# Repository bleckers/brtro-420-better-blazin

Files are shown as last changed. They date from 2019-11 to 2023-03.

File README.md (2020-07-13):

# BRTRO-420 Better Blazin' Mod

### IMPORTANT! A user has reported an issue where the firmware can lockup under certain electrical conditions and cause a dangerously high temperature in the oven. A 1.04 release has been issued to include a watchdog and brownout reset to prevent this. Please update to at least the 1.04 release before operating!

Instructions are available in the wiki - https://github.com/bleckers/brtro-420-better-blazin/wiki

Now available on Tindie as a limited run - https://www.tindie.com/products/blecky/brtro-420-better-blazin-mod/



Modify the [BRTRO-420](http://www.charmhigh-tech.com/sale-7840318-hot-2500w-reflow-oven-brt-420-charmhigh-hot-air-infrared-300-300mm-soldering-rework-station.html) reflow oven to have an Arduino based reflow firmware, serial interface, cold junction compensation and zero crossing detection. This mod consists of a board that connects to the existing controller board, which replaces all the control circuitry and microcontroller.

This oven has a few unique features over the popular T-962 oven, which makes it slightly more desirable if you don't mind the higher cost:
 - an internal convection fan built in.
 - a fume exhaust system which you can vent outside.
 - insulation and thermal tape is actually decent, so it doesn't give of nasty smells during operation.
 - overall build quality is much better.
 
However, unlike the [Unified Engineering mods](https://github.com/UnifiedEngineering/T-962-improvements) to the T-692, the BRTRO-420 is slightly more difficult to modify, mostly due to the [unobtainium build chain](https://hackaday.io/project/167324-brtro-420-better-blazin-mod/log/167780-whats-going-to-happen) for its microcontroller along with a few other design issues such as a poor and noisy thermocouple interface. So the decision was made to spin up a mod board that can be soldered to the bottom of the existing board. This mod board is based on the ATSAMC21 which is a native 5V ARM processor, so it works well with the existing interfaces, without requiring level conversion.

The new firmware keeps the same profile nomenclature as the original oven, so there isn't too much adjustment to the new firmware. However, it is completely written from scratch, so the profile modification workflow is a bit easier now. Note, to change the temperature in the profile edit menu, you hold the OK button on the value you want to edit and then you press the UP/DOWN arrows to adjust the value. Settings are stored automatically once exiting the profile editing screen (you will get a notification on the screen about settings being stored). 

Mod Image

Blog entries about the project are here - https://hackaday.io/project/167324-brtro-420-better-blazin-mod

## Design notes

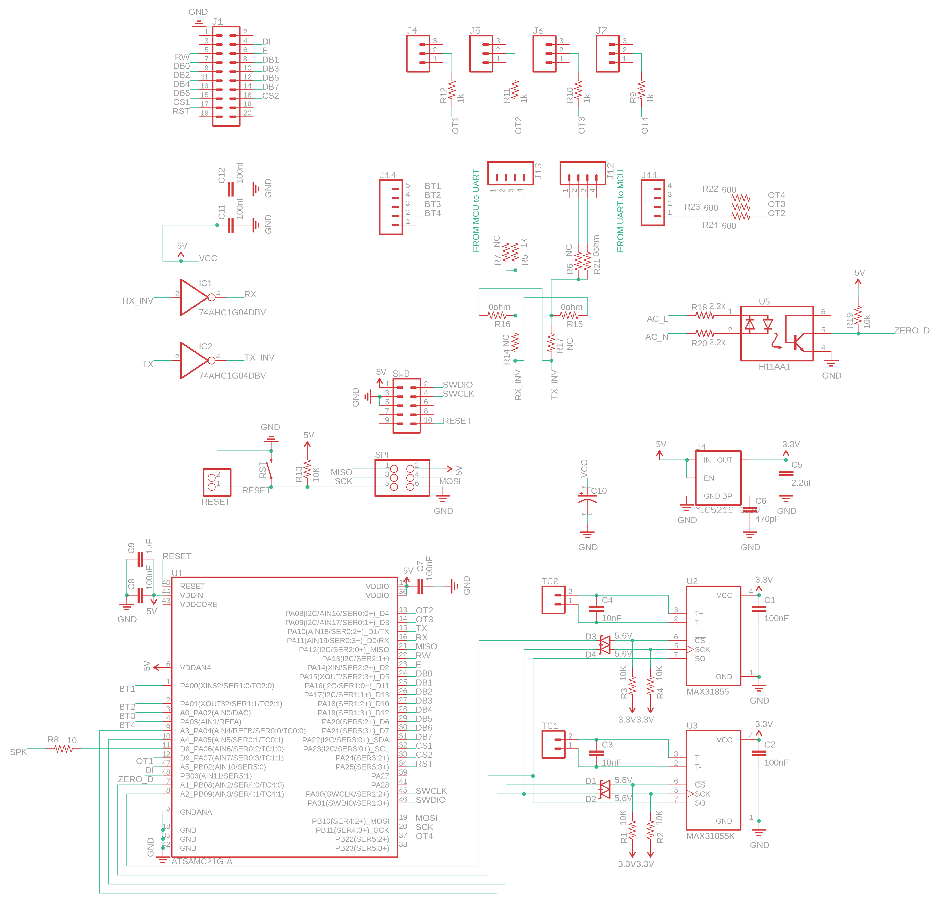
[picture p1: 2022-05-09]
schematic.png

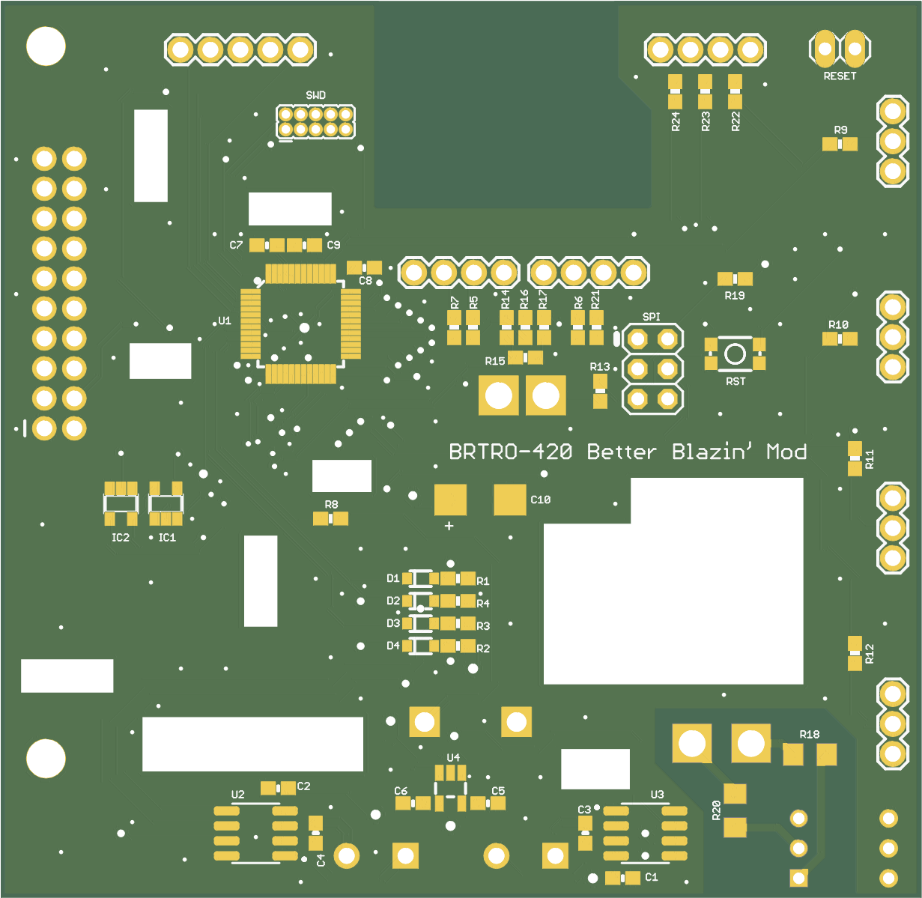
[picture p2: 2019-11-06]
board-gerbers_Combined_Top.png

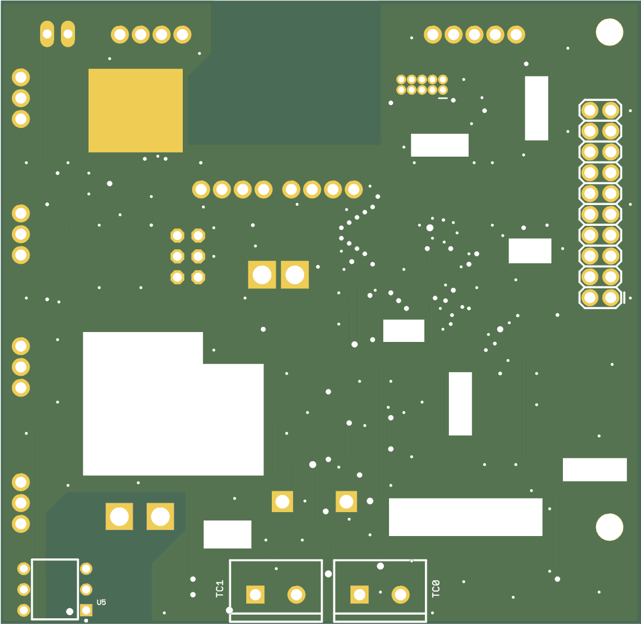
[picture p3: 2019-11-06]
board-gerbers_Combined_Bottom.png

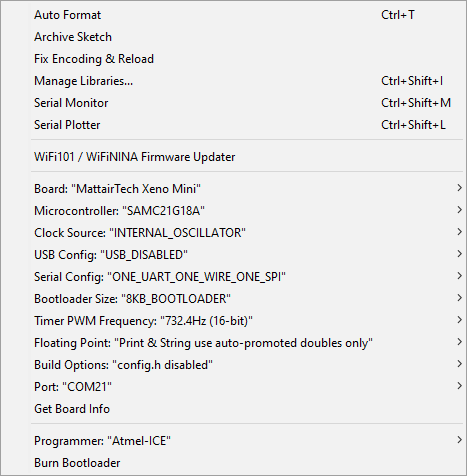
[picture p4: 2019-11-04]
settings.png

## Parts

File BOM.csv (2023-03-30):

Qty | Value | Device | Package | Parts | Description
2 |  | CONN_025MM | SCREWTERMINAL-5MM-2 | TC0, TC1 | Multi connection point. Often used as Generic Header-pin footprint for 0.1 inch spaced/style header connections
1 | 47uF | CPOL-USC/6032-28R | C/6032-28R | C10 | POLARIZED CAPACITOR, American symbol
3 | 0ohm | RESISTOR0603-RES | 0603-RES | R15, R16, R21 | Resistor
1 | 10ohm | RESISTOR0603-RES | 0603-RES | R8 | Resistor
4 | 100nF | CAP0603-CAP | 0603-CAP | C1, C2, C7, C8 | Capacitor
5 | 10K | RESISTOR0603-RES | 0603-RES | R1, R2, R3, R4, R13, R19 | Resistor
2 | 10nF | CAP0603-CAP | 0603-CAP | C3, C4 | Capacitor
4 | 1k | RESISTOR0603-RES | 0603-RES | R5, R9, R10, R11, R12 | Resistor
1 | 1uF | CAP0603-CAP | 0603-CAP | C9 | Capacitor
2 | 2.2k | R-US_R1206 | R1206 | R18, R20 | RESISTOR, American symbol
1 | 2.2uF | CAP0603-CAP | 0603-CAP | C5 | Capacitor
1 | 470pF | CAP0603-CAP | 0603-CAP | C6 | Capacitor
4 | MMSZ5232BS-7-F | 5.6V Zener DIODE | SOD-323 | D1, D2, D3, D4 | Zener Diode
4 | 600 | RESISTOR0603-RES | 0603-RES | R22, R23, R24 | Resistor
2 | 74AHC1G04DBV Or Equivalent | 74AHC1G04DBV | SOT23-5 | IC1, IC2 | INVERTER Gate
1 | ATSAMC21G18A | ATSAMC21G-A | TQFP-48 | U1 | Atmel SAMD21G SMART ARM-Based Microcontroller
1 | H11AA1 | H11AA1 | DIP762W50P254L730H410Q6 | U5 | Optocoupler
2 | MAX31855K | MAX31855K | SOIC127P600X175-8N | U2,U3 | Cold-Junction Compensated Thermocouple-to-Digital Converter
1 | MIC5219 3.3V | V_REG_MIC52193.3V | SOT23-5 | U4 | V_REG MIC5219
1 | MOMENTARY-SWITCH-SPST-SMD-4.6X2.8MM | MOMENTARY-SWITCH-SPST-SMD-4.6X2.8MM | TACTILE_SWITCH_SMD_4.6X2.8MM | S1 | Momentary Switch (Pushbutton) - SPST
3 | NC | RESISTOR0603-RES | 0603-RES | R7, R14, R17,R6 | Resistor

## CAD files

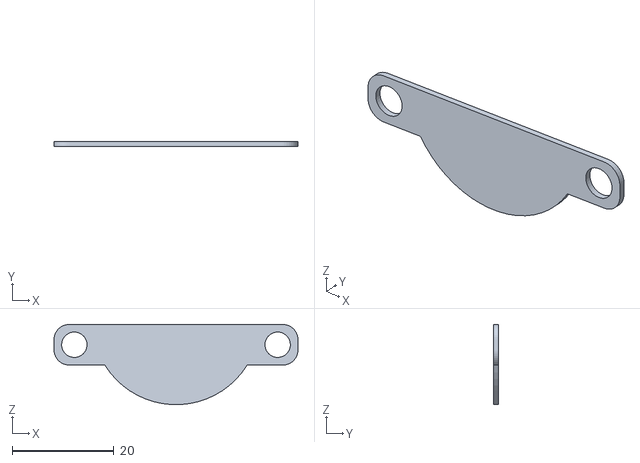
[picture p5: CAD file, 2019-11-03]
fanshim.STL
48.0 x 1.00 x 15.8

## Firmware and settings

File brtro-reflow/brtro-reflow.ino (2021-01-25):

#include "MAX31855soft.h" //https://github.com/enjoyneering/MAX31855
#include <U8g2lib.h> //https://github.com/olikraus/u8g2
//#include "splash-brt.h"
#include "splash-chm.h"
#include "helper.h"
#include "FlashStorage.h"
#include "PID_v1.h"
#include "pidautotuner.h"
#include "variables.h"
#include "menu.h"
#include "serial.h"
#include "watchdog.h"

#define VERSION "V1.04"

bool watchdogReset = false;

double shouldBeTemp;
uint8_t thermocoupleFailCount = 0;

uint8_t fanValue;
uint8_t heaterValueChan0;

double SetpointChan0;
double InputChan0;
double OutputChan0;

uint8_t heaterValueChan1;

double SetpointChan1;
double InputChan1;
double OutputChan1;

PID3_t heaterPIDChan0 = { PID_KP_PREHEAT_C0, PID_KI_PREHEAT_C0, PID_KD_PREHEAT_C0, PID_KP_SOAK_C0, PID_KI_SOAK_C0, PID_KD_SOAK_C0, PID_KP_REFLOW_C0, PID_KI_REFLOW_C0, PID_KD_REFLOW_C0 };
PID3_t heaterPIDChan1 = { PID_KP_PREHEAT_C1, PID_KI_PREHEAT_C1, PID_KD_PREHEAT_C1, PID_KP_SOAK_C1, PID_KI_SOAK_C1, PID_KD_SOAK_C1, PID_KP_REFLOW_C1, PID_KI_REFLOW_C1, PID_KD_REFLOW_C1 };
PID_t fanPID    = { 10.00, 0.03, 10.00 }; //{ 1.00, 0.03, 10.00 };

PID PIDChan0(&InputChan0, &OutputChan0, &SetpointChan0, heaterPIDChan0.Kp_PREHEAT, heaterPIDChan0.Ki_PREHEAT, heaterPIDChan0.Kd_PREHEAT, DIRECT);

PIDAutotuner tunerChan0 = PIDAutotuner();

PID PIDChan1(&InputChan1, &OutputChan1, &SetpointChan1, heaterPIDChan1.Kp_PREHEAT, heaterPIDChan1.Ki_PREHEAT, heaterPIDChan1.Kd_PREHEAT, DIRECT);

PIDAutotuner tunerChan1 = PIDAutotuner();

StoredVar storedVar;

int currentState = IDLEM;

double rampRateChan0 = 0;
double rampRateChan1 = 0;

volatile int frontState = 0;
volatile int backState = 0;
volatile int convectionState = 0;
volatile int exhaustState = 0;

extern U8G2_KS0108_128X64_F u8g2;
extern U8G2LOG u8g2log;
extern uint8_t u8log_buffer[];
extern int errorTimeout;

bool beepState = true;

bool saved = true;
int writeTimeout = -1;
FlashStorage(storedVarFlash, StoredVar);

MAX31855soft MAX31855_0(CSU2, SO, SCK);
MAX31855soft MAX31855_1(CSU3, SO, SCK);

double tc0History[NUMBER_OF_TEMP_AVERAGES] = {0};
double tc1History[NUMBER_OF_TEMP_AVERAGES] = {0};

int averagesCount = 0;

int tempHistoryHead = 0;

double tc0Temp; //Back by default
double tc1Temp; //Front by default
double backTemp;
double frontTemp;
int tcState = 0; //0 normal (Back == TC0, Front == TC1), 1 swapped (Back == TC1, Front == TC0), 2 averaging (Back=Front=(TC0+TC1)/2)

double tc0PrevTemp;
double tc1PrevTemp;

int tc0Detect = MAX31855_THERMOCOUPLE_OK;
int tc1Detect = MAX31855_THERMOCOUPLE_OK;

int currentProfile = 1;
ReflowProfile profiles[MAX_PROFILES + 1]; //Don't use 0 profile

double boardTemp;

int currentMenuID = 0;

unsigned long reflowStartTime = 0;

#define buttonStateTimeout 5

volatile int buttonStatePLUS = 0;
volatile int buttonStateMINUS = 0;
volatile int buttonStateBACK = 0;
volatile int buttonStateOK = 0;

int menuState = 0;
int prevMenuState = 0;
int buttonBACK = 1;
int prevButtonBACK = 1;
unsigned long previousTimeUpdateTemp = 0;
unsigned long previousTimeReadTemp = 0;

int enableMenu = 1;

bool celsiusMode = true; //true is celcius, false is farenheit

int reflow = 0;
unsigned long previousTimeReflowDisplayUpdate = 0;
unsigned long currentReflowSeconds = 0;
unsigned long previousTempDisplayUpdate = 0;

unsigned long prevTempLoopMillis;
unsigned long currentTempLoopMillis;

unsigned long secondsMillisStartChan0;
unsigned long secondsMillisStartChan1;

unsigned long startStateMillis;

int previousState = IDLEM;

uint32_t lastRampTicks;

double startTemp = 0;

bool valueChanged = false;
int profileValueBeingEdited = 0;

int previousSavedProfile;

int currentPIDEditSelection = 0;

unsigned long pollRate = 1000;

double previousRateDisplayTemp0 = 0;

double previousRateDisplayTemp1 = 0;

boolean tuning = false;

boolean currentStateAutotuned = false;

boolean debug = false;

void plusPress()
{
  if (buttonStatePLUS == 0)
    buttonStatePLUS = buttonStateTimeout;
}

void minusPress()
{
  if (buttonStateMINUS == 0)
    buttonStateMINUS = buttonStateTimeout;
}

void okPress()
{
  if (buttonStateOK == 0)
    buttonStateOK = buttonStateTimeout;
}

void zeroCrossing()
{
  int state = digitalRead(ZER_D);

  if (state == 0) //We're in falling
  {
    if (frontState == 1) //Turn on
    {
      digitalWrite(FRONT_HEATER, 0);
    }
    if (backState == 1) //Turn on
    {
      digitalWrite(BACK_HEATER, 0);
    }
    if (convectionState == 1) //Turn on
    {
      digitalWrite(CONVECTION, 0);
    }
    if (exhaustState == 1) //Turn on
    {
      digitalWrite(EXHAUST, 0);
    }
  } else { //We're in rising
    if (frontState == 0)
    { //Turn off
      digitalWrite(FRONT_HEATER, 1);
    }
    if (backState == 0)
    { //Turn off
      digitalWrite(BACK_HEATER, 1);
    }
    if (convectionState == 0)
    { //Turn off
      digitalWrite(CONVECTION, 1);
    }
    if (exhaustState == 0)
    { //Turn off
      digitalWrite(EXHAUST, 1);
    }
  }
}

void loadSettings()
{
  for (int i = 0; i < MAX_PROFILES; i++)
  {
    profiles[i + 1].PreHtTemp = storedVar.profiles[i].PreHtTemp;
    profiles[i + 1].HeatTemp = storedVar.profiles[i].HeatTemp;
    profiles[i + 1].RefTemp = storedVar.profiles[i].RefTemp;
    profiles[i + 1].RefKpTemp = storedVar.profiles[i].RefKpTemp;
    profiles[i + 1].CoolTemp = storedVar.profiles[i].CoolTemp;

    profiles[i + 1].PreHtTime = storedVar.profiles[i].PreHtTime;
    profiles[i + 1].HeatTime = storedVar.profiles[i].HeatTime;
    profiles[i + 1].RefTime = storedVar.profiles[i].RefTime;
    profiles[i + 1].RefKpTime = storedVar.profiles[i].RefKpTime;
    profiles[i + 1].CoolTime = storedVar.profiles[i].CoolTime;
  }

  heaterPIDChan0.Kp_PREHEAT = storedVar.KpChan0_PREHEAT;
  heaterPIDChan0.Ki_PREHEAT = storedVar.KiChan0_PREHEAT;
  heaterPIDChan0.Kd_PREHEAT = storedVar.KdChan0_PREHEAT;
  heaterPIDChan1.Kp_PREHEAT = storedVar.KpChan1_PREHEAT;
  heaterPIDChan1.Ki_PREHEAT = storedVar.KiChan1_PREHEAT;
  heaterPIDChan1.Kd_PREHEAT = storedVar.KdChan1_PREHEAT;

  heaterPIDChan0.Kp_SOAK = storedVar.KpChan0_SOAK;
  heaterPIDChan0.Ki_SOAK = storedVar.KiChan0_SOAK;
  heaterPIDChan0.Kd_SOAK = storedVar.KdChan0_SOAK;
  heaterPIDChan1.Kp_SOAK = storedVar.KpChan1_SOAK;
  heaterPIDChan1.Ki_SOAK = storedVar.KiChan1_SOAK;
  heaterPIDChan1.Kd_SOAK = storedVar.KdChan1_SOAK;

  heaterPIDChan0.Kp_REFLOW = storedVar.KpChan0_REFLOW;
  heaterPIDChan0.Ki_REFLOW = storedVar.KiChan0_REFLOW;
  heaterPIDChan0.Kd_REFLOW = storedVar.KdChan0_REFLOW;
  heaterPIDChan1.Kp_REFLOW = storedVar.KpChan1_REFLOW;
  heaterPIDChan1.Ki_REFLOW = storedVar.KiChan1_REFLOW;
  heaterPIDChan1.Kd_REFLOW = storedVar.KdChan1_REFLOW;

  tcState = storedVar.tcState;

  celsiusMode = storedVar.celsiusMode;

  beepState = storedVar.beepState;

  PIDChan0.SetTunings(heaterPIDChan0.Kp_PREHEAT, heaterPIDChan0.Ki_PREHEAT, heaterPIDChan0.Kd_PREHEAT);
  PIDChan1.SetTunings(heaterPIDChan1.Kp_PREHEAT, heaterPIDChan1.Ki_PREHEAT, heaterPIDChan1.Kd_PREHEAT);

  currentProfile = storedVar.profile;
}

void checkSerial()
{
  while (Serial.available())
  {
    char c = Serial.read();
    if (c == '#')
    {
      /* Set bootloader check value and reboot */
      BOOT_MAGIC_VALUE = BOOT_MAGIC_BOOTLOADER_ENABLE;
      NVIC_SystemReset();//software reset
    }
    else if (c == 'R') //Command to reset for debug purposes
    {
      BOOT_MAGIC_VALUE = 0;
      NVIC_SystemReset();//software reset
    }
    else if (c == 'T') //Print Temps
    {
      if (celsiusMode) Serial.print(backTemp);
      else Serial.print(cToF(backTemp));
      Serial.print(",");
      if (celsiusMode) Serial.println(frontTemp);
      else Serial.println(cToF(frontTemp));
    }
    else if (c == ' ' || c == 'c' || c == 'C') //OK: Spacebar Pressed (or c)
    {
      buttonStateOK = 1; //Will trigger next loop
    }
    else if (c == 'b' || c == 'B' || c == 'v' || c == 'V') //Back: b pressed (or v)
    {
      buttonStateBACK = buttonStateTimeout; //Will trigger next loop (note this is handled differently to other buttons
    }
    else if (c == 'p' || c == 'P' || c == 'z' || c == 'Z') //Plus: p pressed (or z)
    {
      buttonStatePLUS = 1; //Will trigger next loop
    }
    else if (c == 'm' || c == 'M' || c == 'x' || c == 'X') //Minus: m pressed (or x)
    {
      buttonStateMINUS = 1; //Will trigger next loop
    }
    else if (c == '*')
    {
      debug = true;
    }
    else if (c == '8')
    {
      debug = false;
    }
    else if (c == 'A' && debug) //All outputs on for testing (will auto turn off in rest of code)
    {
      frontState = 1;
      digitalWrite(FRONT_HEATER, 0);
      backState = 1;
      digitalWrite(BACK_HEATER, 0);
      convectionState = 1;
      digitalWrite(CONVECTION, 0);
      exhaustState = 1;
      digitalWrite(EXHAUST, 0);
      digitalWrite(SPK, 1);
    }
    else if (c == '~') //Print screen to XBM
    {
      Serial.println("");
      Serial.println("");
      u8g2.writeBufferXBM(Serial); //Requires u8g2 v2.27 (latest from https://github.com/olikraus/U8g2_Arduino)
      Serial.println("");
      Serial.println("");
    }
  }
}

void setup()
{
  //Set the outputs first to prevent powering on elements
  setOutputs();

  /* \/ \/ \/ Keep below here \/ \/ \/ */
  /* Protect against bad code requiring ICSP flashing, do not remove */
  /* This allows us to hold # on startup if we had a bad flash */
  Serial.begin(115200);
  int countdown = 1000;
  while (countdown > 0)
  {
    checkSerial();
    countdown--;
    delay(1);
  }
  /* /\ /\ /\ Keep above here /\ /\ /\ */

  if (RSTC->RCAUSE.reg == RSTC_RCAUSE_WDT) {
    Serial.println("Reset requested by Watchdog");
    watchdogReset = true;
  }
  if (RSTC->RCAUSE.reg == RSTC_RCAUSE_BODVDD) {
    Serial.println("Reset requested by BOD");
    watchdogReset = true;
  }

  bod_setup();
  watchdog_setup();

  u8g2.begin();
  //u8g2.clearBuffer();

  u8g2.drawXBM(0, 0, splash_width, splash_height, splash_bits);

  u8g2.setFont(u8g2_font_profont11_mr); // set the font for the terminal window
  u8g2.drawStr(98, 59, VERSION);

  u8g2.sendBuffer();

  u8g2.setFont(u8g2_font_tom_thumb_4x6_mf); // set the font for the terminal window

  u8g2log.begin(U8LOG_WIDTH, U8LOG_HEIGHT, u8log_buffer); // connect to u8g2, assign buffer
  u8g2log.setLineHeightOffset(0);                         // set extra space between lines in pixel, this can be negative
  //u8g2log.setRedrawMode(0);   // 0: Update screen with newline, 1: Update screen for every char

  attachInterrupt(digitalPinToInterrupt(PLUS), plusPress, FALLING);
  attachInterrupt(digitalPinToInterrupt(MINUS), minusPress, FALLING);
  attachInterrupt(digitalPinToInterrupt(OK), okPress, FALLING);

  //BACK button is not on interrupt

  attachInterrupt(digitalPinToInterrupt(ZER_D), zeroCrossing, CHANGE);

  /* start MAX31855 */
  MAX31855_0.begin();
  MAX31855_1.begin();

  /* Get EEPROM Settings */
  storedVar = storedVarFlash.read();
  if (storedVar.valid == false) //Should be false after new code write
  {
    restoreDefaults(&storedVar);
  }

  loadSettings();

  previousSavedProfile = currentProfile; //Used to reduce writes to flash on a common menu function

  PIDChan0.SetOutputLimits(0, 100); // max output 100%
  PIDChan0.SetMode(AUTOMATIC);

  PIDChan1.SetOutputLimits(0, 100); // max output 100%
  PIDChan1.SetMode(AUTOMATIC);

  delay(2000);

  u8g2.clearBuffer();

  drawScreen();
  drawMenu(0); //Draw main menu
  drawMenuBox(0);
  drawProfile(profiles, tc1Temp, currentProfile);

  u8g2.sendBuffer();
}
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
void loop()
{
  /* Back button not on interrupt */
  buttonBACK = digitalRead(BACK);
  if (buttonBACK == 0 && prevButtonBACK == 1 && buttonStateBACK == 0)
  {
    buttonStateBACK = buttonStateTimeout;
  }

  prevButtonBACK = buttonBACK;

  if (buttonStateMINUS == 1 && buttonStatePLUS == 1)
  {
    //Ignore
  }
  else if (buttonStateMINUS == 1)
  {
    if (debug) Serial.println("Minus Pressed");
    if (enableMenu == 1)
    {
      prevMenuState = menuState;

      if (currentMenuID == 5)
      {
        if (menuState == 2 && digitalRead(OK) == 0)
        {
          delay(1); //noise reduction delay
          if (digitalRead(OK) == 0)
          {
            editProfileTemp(profileValueBeingEdited, profiles, currentProfile, false);
            profileEdited();
          }
        }
        else if (menuState == 4 && digitalRead(OK) == 0)
        {
          delay(1); //noise reduction delay
          if (digitalRead(OK) == 0)
          {
            editProfileTime(profileValueBeingEdited, profiles, currentProfile, false);
            profileEdited();
          }
        } else {
          menuState = 4; //We're in profile edit mode
        }
      } else {

        menuState++;
        if (menuState > 4)
          menuState = 4;
      }
    }
  }
  else if (buttonStatePLUS == 1)
  {
    if (debug) Serial.println("Plus Pressed");
    if (enableMenu == 1)
    {
      prevMenuState = menuState;
      if (currentMenuID == 5)
      {
        if (menuState == 2 && digitalRead(OK) == 0)
        {
          delay(1); //noise reduction
          if (digitalRead(OK) == 0)
          {
            profileEdited();
            editProfileTemp(profileValueBeingEdited, profiles, currentProfile, true);
          }
        }
        else if (menuState == 4 && digitalRead(OK) == 0)
        {
          delay(1); //noise reduction delay
          if (digitalRead(OK) == 0)
          {
            editProfileTime(profileValueBeingEdited, profiles, currentProfile, true);
            profileEdited();
          }
        } else {
          menuState = 2;
        }
      } else {
        menuState--;
        if (menuState < 0)
          menuState = 0;
      }
    }
  }

  if (buttonStateOK == 1)
  {
    if (watchdogReset) {
      watchdogReset = false; //Keep watchdog message until OK pressed
    } else {

      //Use top bar as info bar and use TOP display as state progress
      //Also draw profile as we go
      if (debug) Serial.println("OK Pressed");
      if (beepState) buzzer(SPK);
      if (currentMenuID == 0)
      {
        switch (menuState)
        {
          case 0: //Config
            {
              currentMenuID = 1;
              break;
            }
          case 1: //Profile Number
            {
              currentProfile++;
              if (currentProfile > 9)
                currentProfile = 1;
              drawProfile(profiles, tc1Temp, currentProfile);
              storedVar.profile = currentProfile;
              if (previousSavedProfile != currentProfile)
              {
                writeTimeout = 10000;
                saved = false;
              } else {
                saved = true;
              }
              break;
            }
          case 2: //Profile
            {
              currentMenuID = 2;
              break;
            }
          case 3: //Tools
            {
              currentMenuID = 3;
              break;
            }
          case 4: //Start
            {
              if (backTemp < START_TEMP_MAX && frontTemp < START_TEMP_MAX)
              {
                thermocoupleFailCount = 0;

                drawProfile(profiles, tc1Temp, currentProfile);
                u8g2.updateDisplay();

                currentMenuID = 4;

                //Update menu each second
                enableMenu = 0;

                Serial.println("");
                Serial.print("Reflow software version: ");
                Serial.println(VERSION);

                serialPrintProfile(tcState, currentProfile, profiles, heaterPIDChan0, heaterPIDChan1, celsiusMode);

                startReflow();
              } else {
                u8g2log.print("\fERR:Temp >50");
                printError();
              }
              break;
            }
        }
      }
      else if (currentMenuID == 4) //We're in reflow
      {
        enableMenu = 1;
        currentMenuID = 0;

        if (tuning == true)
        {
          Serial.println("Tuning Cancelled");
          u8g2log.print("\fTuning Cancelled");
        } else {
          Serial.println("Reflow Cancelled");
          u8g2log.print("\fReflow Cancelled");
        }

        if (tuning == true)
        {
          tuning = false;
        }

        disableReflow();

        printError();
      }
      else if (currentMenuID == 2) //Editing profile value
      {
        currentMenuID = 5;

        //Value being edited
        profileValueBeingEdited = menuState;

        if (menuState != 2 && menuState != 4)
        {
          if (menuState < 2) { // Goto nearest valid menu item
            prevMenuState = 2;
            menuState = 2;
          } else  {
            prevMenuState = 4;
            menuState = 4;
          }
        }
      }
      else if (currentMenuID == 5) //Editing a profile value
      {
        //Handled in plus/minus button
      }
      else if (currentMenuID == 3) //Tools Menu
      {
        switch (menuState)
        {
          case 0: //Tune
            if (backTemp < START_TEMP_MAX && frontTemp < START_TEMP_MAX)
            {
              if (tuning != true) { //Set the output to the desired starting frequency.
                Serial.println("");
                Serial.println("Tuning Started");
                Serial.println("");
                Serial.println("Mode,Seconds,SetPoint,TC0,RateTC0,PWMOut0,TC1,RateTC1,PWMOut1");
                Serial.println("");
                tuning = true;
                currentState = PREHT;

                secondsMillisStartChan0 = millis();
                secondsMillisStartChan1 = millis();

                enableMenu = 0;
                currentMenuID = 4;

                startReflow();

                clearProfile();
                u8g2.updateDisplay();
              }
            } else {
              u8g2log.print("\fERR:Temp >50");
              printError();
            }
            break;
          case 1: //PID
            currentMenuID = 7;
            break;
          case 2: //Test
            currentMenuID = 6;
            break;
          case 3: //Reset
            {
              restoreDefaults(&storedVar);
              loadSettings();
              saved = false;
              writeTimeout = 1000;
            }
        }
      }
      else if (currentMenuID == 6) //Test Menu
      {
        currentState = NONE;
        switch (menuState)
        {
          case 0: //Front
            if (frontState == 0) //Turn on
            {
              frontState = 1;
            } else {
              frontState = 0;
            }
            break;
          case 1: //Back
            if (backState == 0) //Turn on
            {
              backState = 1;
            } else {
              backState = 0;
            }
            break;
          case 2: //Stir
            if (convectionState == 0) //Turn on
            {
              convectionState = 1;
            } else {
              convectionState = 0;
            }
            break;
          case 3: //Vent
            if (exhaustState == 0) //Turn on
            {
              exhaustState = 1;
            } else {
              exhaustState = 0;
            }
            break;
        }
      } else if (currentMenuID == 7) //PID menu
      {
        switch (menuState)
        {
          case 0: //Channel Selection
            currentPIDEditSelection++;
            if (currentPIDEditSelection > 5) currentPIDEditSelection = 0;
            break;
          case 1: //P
            //TODO: Be able to edit these with +/-?
            break;
          case 2: //I
            break;
          case 3: //D
            break;
        }
      } else if (currentMenuID == 1) //Config menu
      {
        switch (menuState)
        {

          case 0: //Temp units
            celsiusMode = !celsiusMode;
            valueChanged = true;
            break;
          case 1: //TC Change
            tcState++;
            if (tcState > 2) tcState = 0;
            valueChanged = true;
            break;
          case 2: //Beep State
            beepState = !beepState;
            valueChanged = true;
        }
      }

      refreshMenu();
      drawMenu(currentMenuID);
      drawMenuBox(menuState);
      u8g2.updateDisplay();
    }
  }
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

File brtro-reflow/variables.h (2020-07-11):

#ifndef _VARIABLES_H
#define _VARIABLES_H

#define START_TEMP_MAX 80
#define NUMBER_OF_TEMP_AVERAGES 6
#define NUMBER_OF_CROSSINGS_AVERAGES 2
#define MAX_PROFILE_TEMP 260



// ******************* DEFAULT PID PARAMETERS *******************
// ***** PRE-HEAT STAGE *****
#define PID_KP_PREHEAT_C0 40 //50.28 //
#define PID_KI_PREHEAT_C0 0.025 //4.78 //
#define PID_KD_PREHEAT_C0 20 //166.72 //

#define PID_KP_PREHEAT_C1 40 //96.98 //
#define PID_KI_PREHEAT_C1 0.025 //26.96 //
#define PID_KD_PREHEAT_C1 20 //210.38 //

// ***** SOAKING STAGE *****
#define PID_KP_SOAK_C0 200 //97.00 //
#define PID_KI_SOAK_C0 0.015 //25.97 //
#define PID_KD_SOAK_C0 50 //168.54 //

#define PID_KP_SOAK_C1 200 //44.30 //
#define PID_KI_SOAK_C1 0.015 //6.56 //
#define PID_KD_SOAK_C1 50 //201.32 //

// ***** REFLOW STAGE *****
#define PID_KP_REFLOW_C0 100 //38.12 //
#define PID_KI_REFLOW_C0 0.025 //2.15 //
#define PID_KD_REFLOW_C0 25 //200.13 //

#define PID_KP_REFLOW_C1 100 //43.01 //
#define PID_KI_REFLOW_C1 0.025 //6.73 //
#define PID_KD_REFLOW_C1 25 //400.31 //

#define MAX_PROFILES 9

typedef struct {
  double Kp_PREHEAT;
  double Ki_PREHEAT;
  double Kd_PREHEAT;

  double Kp_SOAK;
  double Ki_SOAK;
  double Kd_SOAK;

  double Kp_REFLOW;
  double Ki_REFLOW;
  double Kd_REFLOW;
} PID3_t;

typedef struct {
  double Kp;
  double Ki;
  double Kd;
} PID_t;

struct ReflowProfile
{

  //Temp to reach
  int PreHtTemp = 100;
  int HeatTemp = 180;
  int RefTemp = 240;
  int RefKpTemp = 240;
  int CoolTemp = 50;

  //Seconds to try getting to temp
  int PreHtTime = 80;
  int HeatTime = 220;
  int RefTime = 30;
  int RefKpTime = 30;
  int CoolTime = 80;
};

struct StoredVar
{
  bool valid;                //Should be false after new code write (to pull defaults)

  double KpChan0_PREHEAT;
  double KiChan0_PREHEAT;
  double KdChan0_PREHEAT;
  double KpChan1_PREHEAT;
  double KiChan1_PREHEAT;
  double KdChan1_PREHEAT;

  double KpChan0_SOAK;
  double KiChan0_SOAK;
  double KdChan0_SOAK;
  double KpChan1_SOAK;
  double KiChan1_SOAK;
  double KdChan1_SOAK;

  double KpChan0_REFLOW;
  double KiChan0_REFLOW;
  double KdChan0_REFLOW;
  double KpChan1_REFLOW;
  double KiChan1_REFLOW;
  double KdChan1_REFLOW;

  bool celsiusMode;

  uint8_t profile;
  uint8_t tcState;
  uint8_t beepState;
  ReflowProfile profiles[MAX_PROFILES];
};

void restoreDefaults(StoredVar * storedVar)
{
  storedVar->profile = 1;

  storedVar->tcState = 0;

  storedVar->KpChan0_PREHEAT = PID_KP_PREHEAT_C0;
  storedVar->KiChan0_PREHEAT = PID_KI_PREHEAT_C0;
  storedVar->KdChan0_PREHEAT = PID_KD_PREHEAT_C0;
  storedVar->KpChan1_PREHEAT = PID_KP_PREHEAT_C1;
  storedVar->KiChan1_PREHEAT = PID_KI_PREHEAT_C1;
  storedVar->KdChan1_PREHEAT = PID_KD_PREHEAT_C1;

  storedVar->KpChan0_SOAK = PID_KP_SOAK_C0;
  storedVar->KiChan0_SOAK = PID_KI_SOAK_C0;
  storedVar->KdChan0_SOAK = PID_KD_SOAK_C0;
  storedVar->KpChan1_SOAK = PID_KP_SOAK_C1;
  storedVar->KiChan1_SOAK = PID_KI_SOAK_C1;
  storedVar->KdChan1_SOAK = PID_KD_SOAK_C1;

  storedVar->KpChan0_REFLOW = PID_KP_REFLOW_C0;
  storedVar->KiChan0_REFLOW = PID_KI_REFLOW_C0;
  storedVar->KdChan0_REFLOW = PID_KD_REFLOW_C0;
  storedVar->KpChan1_REFLOW = PID_KP_REFLOW_C1;
  storedVar->KiChan1_REFLOW = PID_KI_REFLOW_C1;
  storedVar->KdChan1_REFLOW = PID_KD_REFLOW_C1;
  storedVar->valid = true;
  storedVar->celsiusMode = true;
  storedVar->beepState = true;

  for (int i = 0; i < MAX_PROFILES; i++)
  {

    storedVar->profiles[i].PreHtTemp = 100;
    storedVar->profiles[i].HeatTemp = 180;
    storedVar->profiles[i].RefTemp = 240;
    storedVar->profiles[i].RefKpTemp = 240;
    storedVar->profiles[i].CoolTemp = 60;

    storedVar->profiles[i].PreHtTime = 80;
    storedVar->profiles[i].HeatTime = 180;
    storedVar->profiles[i].RefTime = 60;
    storedVar->profiles[i].RefKpTime = 30;
    storedVar->profiles[i].CoolTime = 80;
  }
}

void editProfileTime(int profileValueBeingEdited, ReflowProfile * profiles, int currentProfile, bool increment)
{
  int value = -1;
  if (increment) value = 1;

  switch (profileValueBeingEdited)
  {
    case PREHT:
      {
        profiles[currentProfile].PreHtTime = profiles[currentProfile].PreHtTime + value;
        if (profiles[currentProfile].PreHtTime < 0) profiles[currentProfile].PreHtTime = 200;
        if (profiles[currentProfile].PreHtTime > 200) profiles[currentProfile].PreHtTime = 0;
        break;
      }
    case HEAT:
      {
        profiles[currentProfile].HeatTime = profiles[currentProfile].HeatTime + value;
        if (profiles[currentProfile].HeatTime < 0) profiles[currentProfile].HeatTime = 200;
        if (profiles[currentProfile].HeatTime > 200) profiles[currentProfile].HeatTime = 0;
        break;
      }
    case REF:
      {
        profiles[currentProfile].RefTime = profiles[currentProfile].RefTime + value;
        if (profiles[currentProfile].RefTime < 0) profiles[currentProfile].RefTime = 200;
        if (profiles[currentProfile].RefTime > 200) profiles[currentProfile].RefTime = 0;
        break;
      }
    case REFKP:
      {
        profiles[currentProfile].RefKpTime = profiles[currentProfile].RefKpTime + value;
        if (profiles[currentProfile].RefKpTime < 0) profiles[currentProfile].RefKpTime = 200;
        if (profiles[currentProfile].RefKpTime > 200) profiles[currentProfile].RefKpTime = 0;
        break;
      }
    case COOL:
      {
        profiles[currentProfile].CoolTime = profiles[currentProfile].CoolTime + value;
        if (profiles[currentProfile].CoolTime < 0) profiles[currentProfile].CoolTime = 200;
        if (profiles[currentProfile].CoolTime > 200) profiles[currentProfile].CoolTime = 0;
        break;
      }
  }
}
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

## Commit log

2019-11-03 Added fan shim STL.
    [fanshim.STL]
2019-11-04 Added board gerbers and BOM
    [BOM.csv, BOM.xlsx]
2019-11-04 Added Arduino board files and bootloader hex.
2019-11-04 Add Arduino board settings.
2019-11-04 Add missing level converter in gerber and BOM
    [BOM.csv, BOM.xlsx]
2019-11-04 Add board renders.
2019-11-04 Add in Fahrenheit temp display. Variables are still handled internally as Celsius, but values will display and print as Fahrenheit
2019-11-05 Better default ramp rates. Small display bux fixes. Reflow safety timer. Tuning bux fixes.
    [brtro-reflow.ino]
2019-11-05 Remove reference to board colour since it is recommended to replace the thermocouples.
    [brtro-reflow.ino]
2019-11-05 Update PNP information.
    [BOM.csv, BOM.xlsx]
2019-11-06 Changed PNP and resistor based inverter to inverter gate.
    [BOM.csv, BOM.xlsx]
2019-11-06 Neaten gerber silkscreen
2019-11-07 Update BOM
    [BOM.csv, BOM.xlsx]
2019-11-09 Check for thermocouple grounded error.
    [brtro-reflow.ino]
2019-11-11 Fixed small negative ramp rate LCD display centering. Fixed current profile storing when not changed.
    [brtro-reflow.ino, helper.h]
2019-11-11 Move some functions to external file and de-boilerplate code.
2019-11-14 Allow disabling of buzzer in config menu.
    [brtro-reflow.ino, menu.h, variables.h]
2019-11-15 Tweak to zero crossing interrupt.
2019-11-17 Add fuses.
2019-11-18 Add startup display version print and print screen function. All previous working testing versions are known as 1.00.
2020-01-05 Fix thermocouple swapping bug and allow single TC in TC averaging mode.
    [brtro-reflow.ino]
2020-02-02 Tweak BOM.
    [BOM.csv, BOM.xlsx]
2020-07-12 Add watchdog reset, brownout reset and max temp safety cutout
    [brtro-reflow.ino]
2020-07-13 Clearer error on LCD, comments for BOD, increase thermocouple fail threshold
    [brtro-reflow.ino]
2022-05-09 Schematic Upload
